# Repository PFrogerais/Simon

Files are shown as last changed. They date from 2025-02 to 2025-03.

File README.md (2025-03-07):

# Démonstration du Jeu Simon – Assemblé & Programmé
Dans cette vidéo, découvrez le jeu **Simon** entièrement assemblé et programmé !  

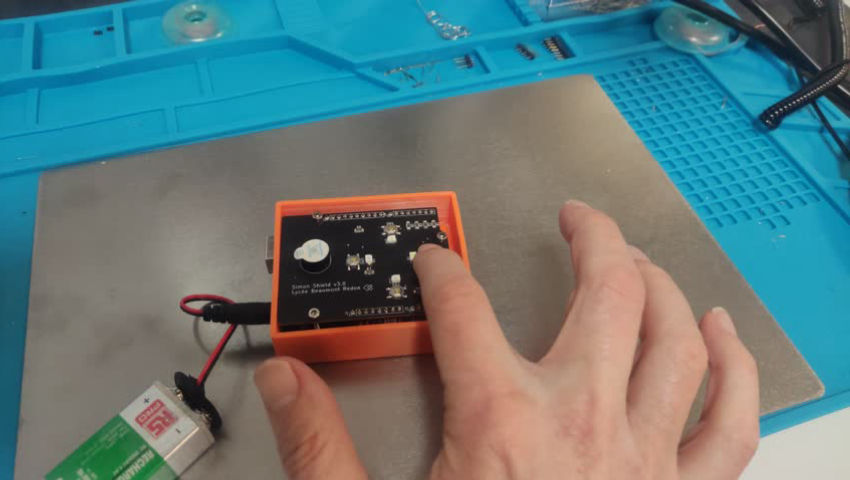
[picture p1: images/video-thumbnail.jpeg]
Voir la démonstration (https://tube-sciences-technologies.apps.education.fr/w/i4Xqwx69rhGFDRBjq2J4fU)


Ce projet, basé sur une carte Arduino, intègre :
- **4 LEDs** et **4 boutons** pour reproduire la séquence du jeu,
- Un **buzzer** pour les signaux sonores,
- Un **boîtier imprimé en 3D** réalisé sur mesure,

# Dossier de conception du shield Arduino

Voici un guide étape par étape pour concevoir et assembler la carte électronique intégrant des composants CMS (résistances et LED montées en surface) ainsi que des composants traversants (comme le connecteur Arduino et le buzzer). Ce procédé  inclut l'application manuelle de pâte à braser et le passage en four à refusion sans utilisation de stencil.

## 1. Génération des Fichiers de Fabrication

- **Fichiers Gerber :**
- Télécharger [fichiers de fabrication gerber Simon3.zip](hardware/kicad/simon3/production/simon3.zip)
- **Fabrication du PCB :**
- Envoyez ces fichiers à un fabricant de PCB (JLCPCB)

## 2. Nomenclature

| Reference | Value |  Qty |
|---|---|----- |
| BZ1 | Buzzer |  1 |
| D1 | LED RED |  1 |
| D2 | LED Green |  1 |
| D3 | LED Blue |  1 |
| D4 | LED Yellow |  1 |
| J1 | Power |  1 |
| J2,J4 | Digital/PWM  |  2 |
| J3 | Analog |  1 |
| R1,R2 | 160 |  2 |
| R3 | 100 |  1 |
| R4 | 150 |  1 |
| R5,R6,R7,R8 | 10k |  4 |
| SW1,SW2,SW3,SW4 | SW_Push |  4 |

[Nomenclature](hardware/kicad/simon3/simon3.csv)

## 4. Préparation à l’Assemblage

- **Nettoyage du PCB :**
  - Assurez-vous que la carte est propre et exempte de poussière ou d’empreintes.
- **Mise en place du poste de travail :**
  - Organisez votre matériel : pâte à braser (en seringue), fer à souder pour les composants traversants, four à refusion.
- **Documentation :**
  - Imprimez le schéma et/ou un plan de positionnement (layout) pour guider le placement des composants.
Implantation

# Brasage des composants

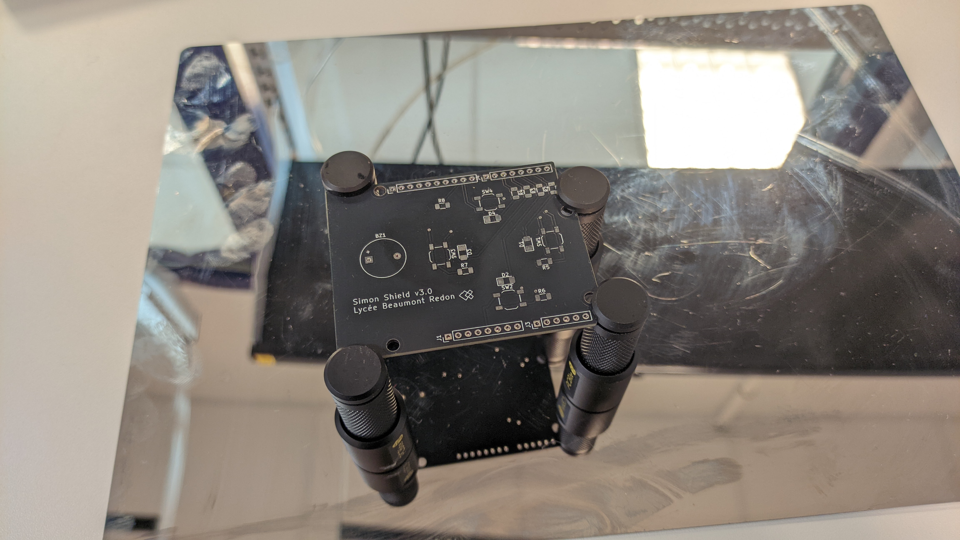
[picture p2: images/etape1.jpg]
carte à braser
 

## 1. Application de la Pâte à Braser (Sans Stencil)

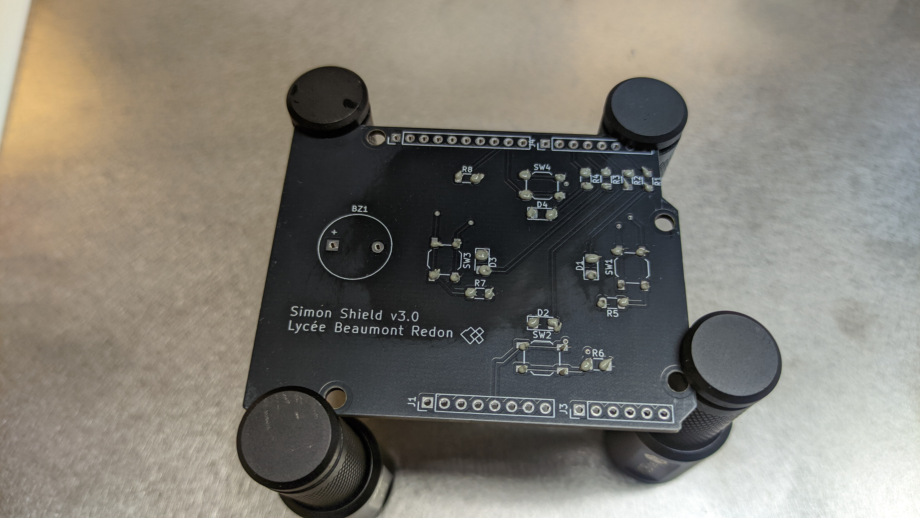
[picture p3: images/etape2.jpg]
Appliquer la pâte
 

- **Utilisation d’une seringue :**
  - À l’aide d’une seringue, déposez manuellement la pâte à braser sur chaque zone de montage des composants CMS.
  - Veillez à appliquer la quantité appropriée pour chaque pad afin d’éviter les ponts de soudure ou les soudures insuffisantes.
- **Précision :**
  - Pour les zones très fines, utilisez une seringue à embout fin et, si besoin, une loupe pour vérifier l’exactitude de l’application.

## 6. Placement des Composants CMS

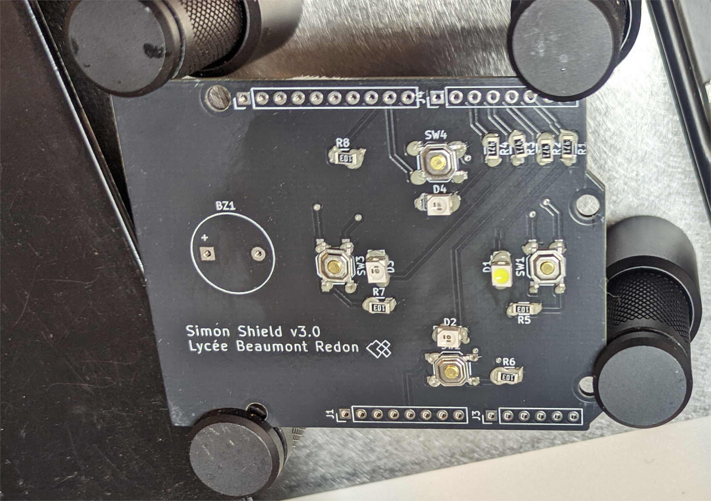
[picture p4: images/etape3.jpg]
Peupler les CMS


- **Positionnement :**
  - Placez délicatement les composants CMS (résistances, LED, etc.) sur les pads recouverts de pâte.
  - Vérifiez l’alignement et l’orientation (notamment pour les composants polarisés comme certaines LED).
- **Ajustement :**
  - Corrigez la position des composants si nécessaire avant le passage en four.

## 7. Passage en Four à Refusion

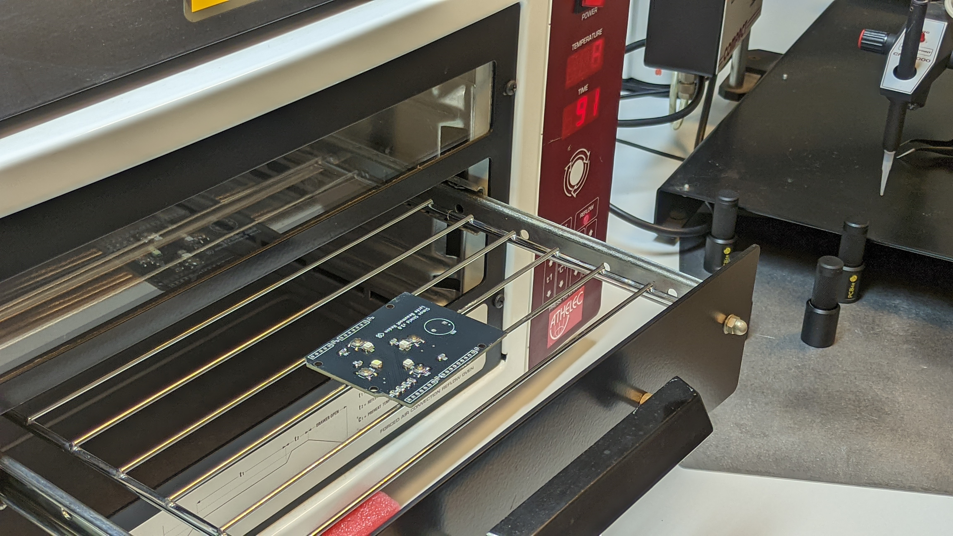
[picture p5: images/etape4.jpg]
Mettrer au four


- **Programmation de la courbe de chauffe :**

  - Programmez le four à refusion selon une courbe de température adaptée (phase de préchauffage, pic de température, et refroidissement contrôlé).

- **Refusion :**
  - Placez la carte dans le four et lancez le cycle.
  - Surveillez le processus pour vous assurer que la pâte à braser fond correctement et forme des joints solides.
- **Refroidissement :**
  - Laissez la carte refroidir progressivement pour éviter les contraintes thermiques.

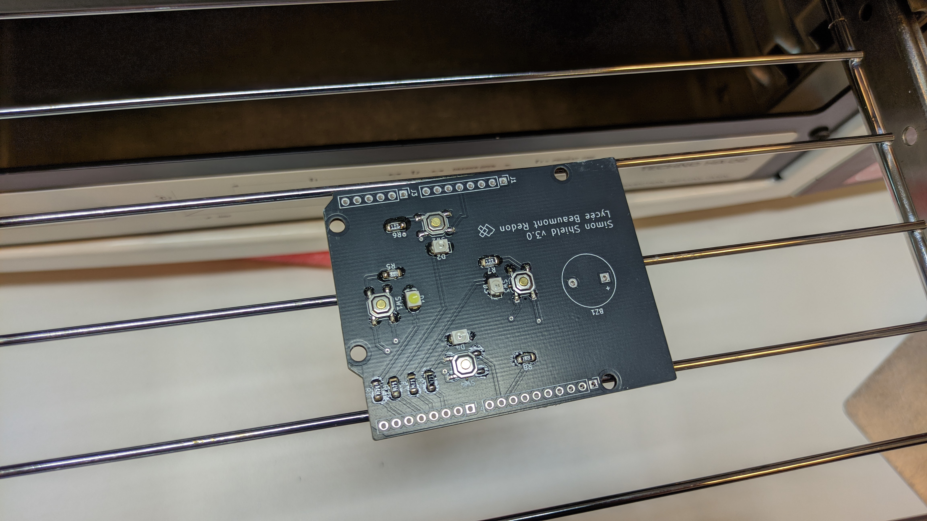
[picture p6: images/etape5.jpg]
Sortir du four


## 8. Soudure des Composants Traversants

- **Placement manuel :**
  - Après la refusion des composants CMS, positionnez les composants traversants (connecteur Arduino, buzzer, etc.) sur la carte.
- **Soudure :**
  - Utilisez un fer à souder pour souder manuellement ces composants.
  - Assurez-vous de réaliser des soudures nettes et sans ponts.
- Utilisation d'une carte Arduino HS pour pour maintenir le shield et les connecteurs 
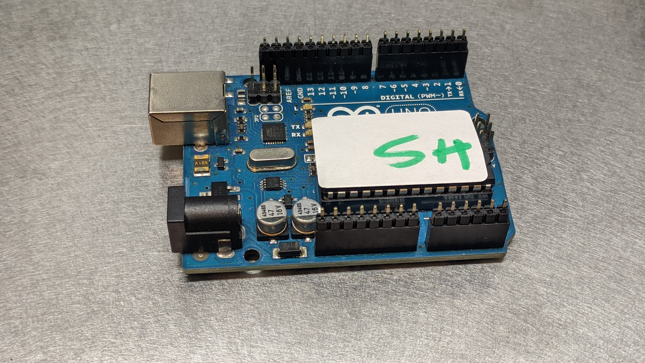
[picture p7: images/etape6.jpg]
Arduino HS

- Placer la carte par dessus 
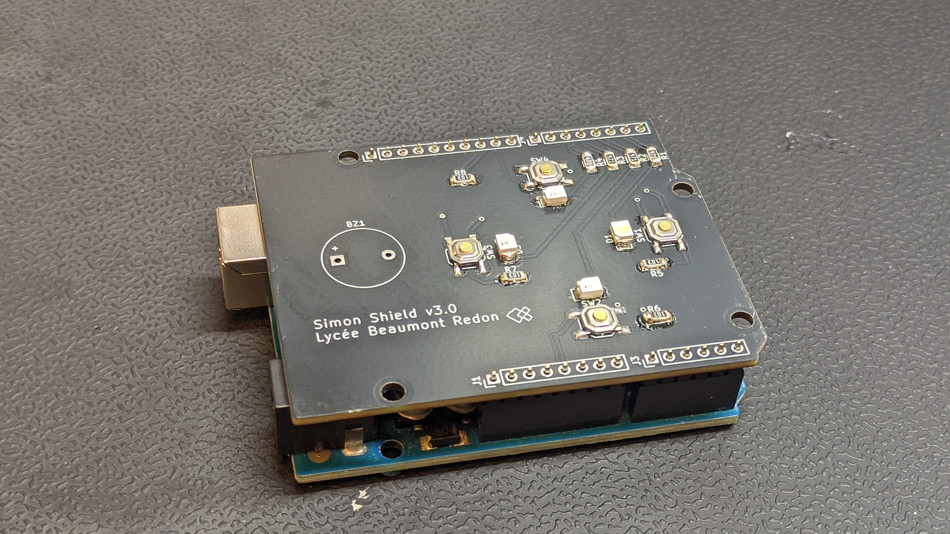
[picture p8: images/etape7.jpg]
Shield maintenu sur l'Arduino UNO

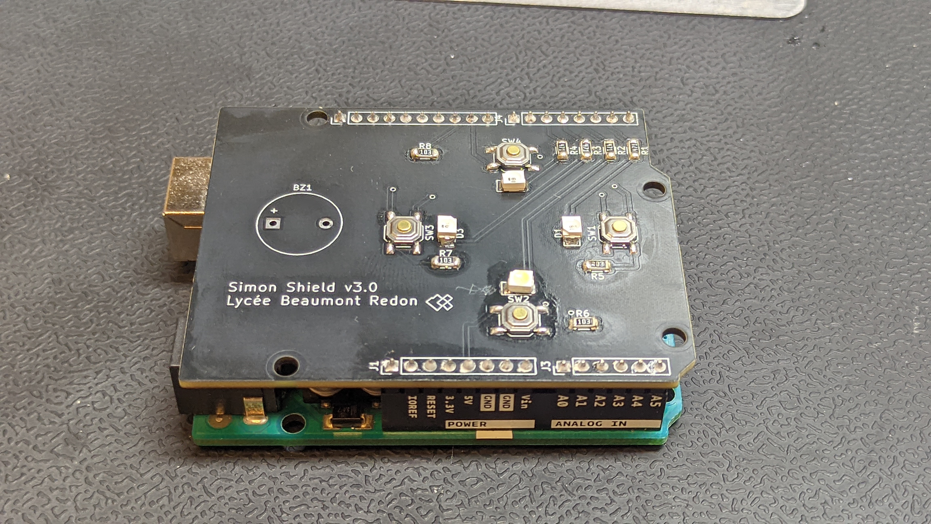
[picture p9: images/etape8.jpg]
Soudure du connecteur

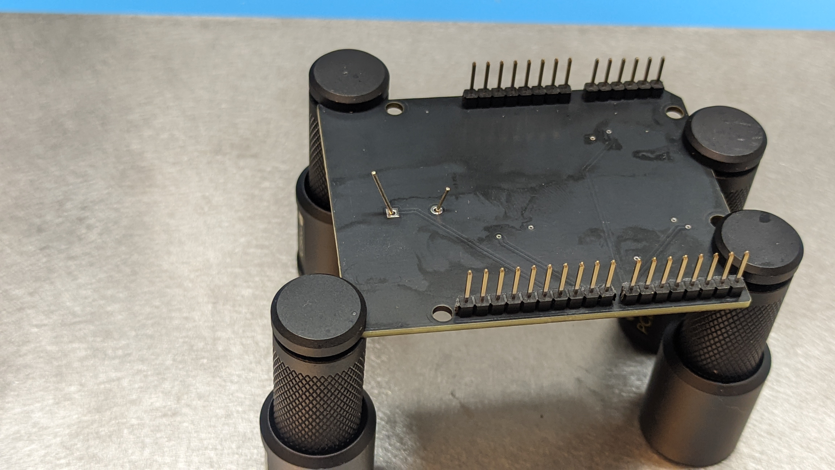
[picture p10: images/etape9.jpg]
Soudure du buzzer


## 9. Inspection et Tests

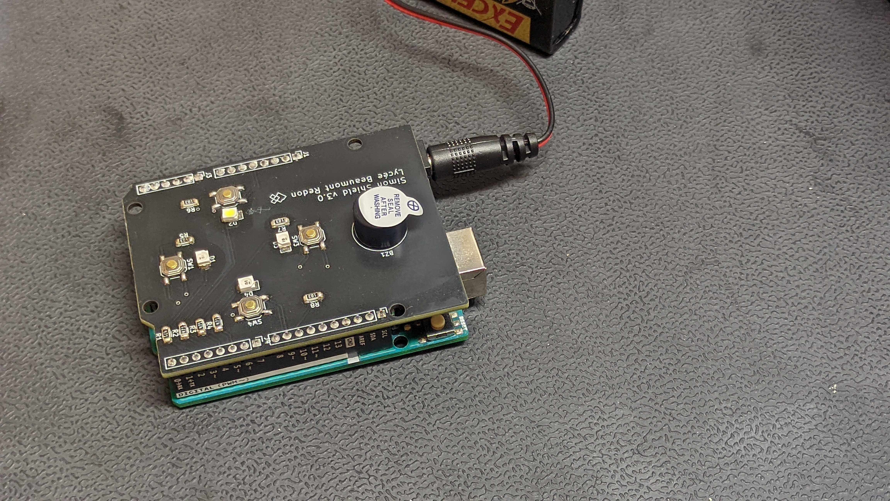
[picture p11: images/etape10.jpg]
Brasures Terminéee


- **Contrôle visuel :**

  - Inspectez la carte à l’aide d’une loupe ou d’un microscope pour vérifier la qualité des soudures (absence de ponts, bonne homogénéité des joints).
- **Retouches éventuelles :**
  - Réalisez des retouches manuelles si vous constatez des défauts.
- **Tests fonctionnels :**
  - Alimentez la carte et vérifiez le bon fonctionnement de l’ensemble du circuit (LED, buzzer, connecteur Arduino).
  - Mesurez les tensions et vérifiez la continuité des pistes si nécessaire.

# Conception du boitier en 3D

Cette section décrit les étapes d'assemblage de votre projet dans un boîtier imprimé en 3D. Le but est de fournir toutes les informations nécessaires pour intégrer les composants électroniques (Arduino UNO, shield, etc.) dans le boîtier final. Le modèle 3D du boîtier, au format STL, est mis à disposition pour que vous puissiez le préparer dans votre logiciel de découpe (slicer) et lancer l'impression 3D.

## Détail des étapes

1. **Modèle 3D du boîtier**

   - **Description :**  
     Vous disposez du fichier STL du boîtier, nommé ici "Boitier Simon". Ce fichier est utilisé avec un slicer pour préparer l'impression 3D de la pièce.
   - **Lien :**  
     [Boitier Simon](hardware/Boitier/simon_box_2-MainBox.stl)  
     En cliquant sur ce lien, vous accédez directement au fichier STL hébergé dans le répertoire `hardware/Boitier/` de votre dépôt GitHub.

2. **Ajouter les inserts à chaud à l'aide d'un fer à souder**

   - **Description :**  

     Avant de monter les composants, il est recommandé d'ajouter des inserts (des éléments métalliques ou en plastique spécialement conçus pour recevoir des vis) dans le boîtier.  
     Pour cela, on utilise un fer à souder qui, en chauffant les inserts, permet de les fixer solidement dans la matière imprimée.
   - **Illustration :**  

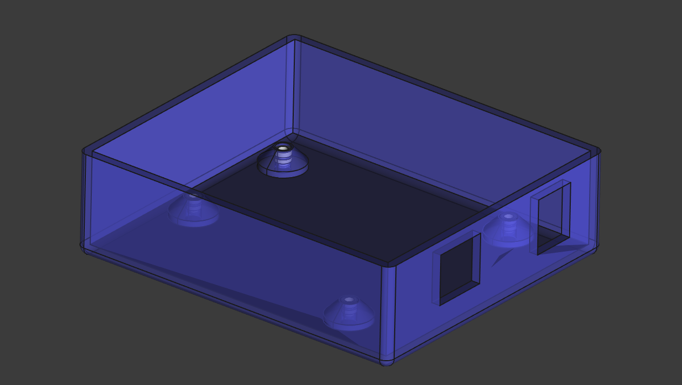
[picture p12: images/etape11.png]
Boitier + insert
      
     Cette image montre le boîtier dans lequel les inserts ont été placés, prêts à recevoir les fixations.

3. **Ajouter la carte Arduino UNO**
   - **Description :**  

     Une fois les inserts en place, la carte Arduino UNO est insérée dans le boîtier.  
     Cette étape assure que l'électronique de base du projet est correctement positionnée et prête à être connectée aux autres composants.

    - **Illustration :**  

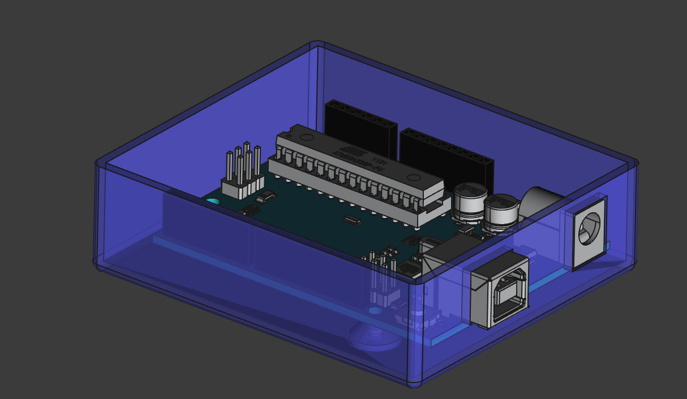
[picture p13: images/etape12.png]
Boitier + insert + UNO
       
     L'image illustre la carte Arduino UNO insérée dans le boîtier, avec les inserts déjà en place.

4. **Ajouter le shield**

   - **Description :**  

     Le shield, qui est une extension pour l'Arduino, est ensuite ajouté sur la carte.  
     Cette étape complète l'intégration de l'électronique, permettant d'ajouter des fonctionnalités supplémentaires (par exemple, gestion d'entrées/sorties, alimentation, etc.).
   - **Illustration :**  
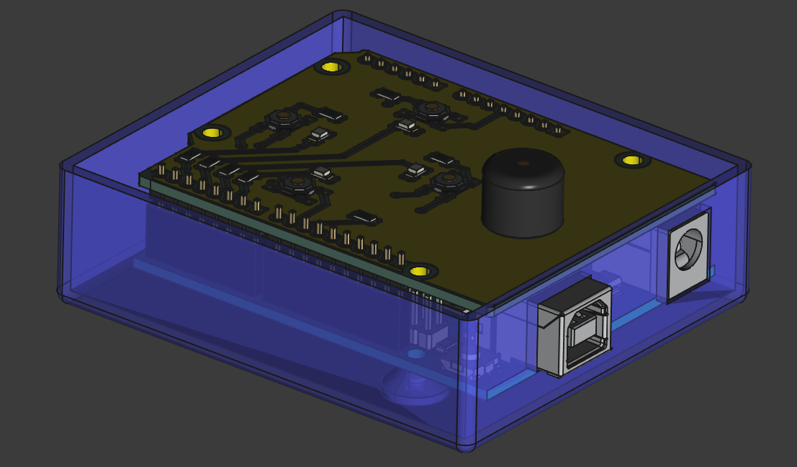
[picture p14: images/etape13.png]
Boitier + insert + UNO+ Shield
     
     L'image montre le boîtier avec la carte Arduino UNO et le shield monté, indiquant l'évolution de l'assemblage.

5. **Visser les 4 vis dans les inserts**

   - **Description :**  
     Pour finaliser l'assemblage, 4 vis sont insérées dans les inserts prévus à cet effet.  
     Ces vis servent à fixer solidement l'ensemble des composants dans le boîtier, garantissant une bonne stabilité mécanique.
   - **Illustration :**  
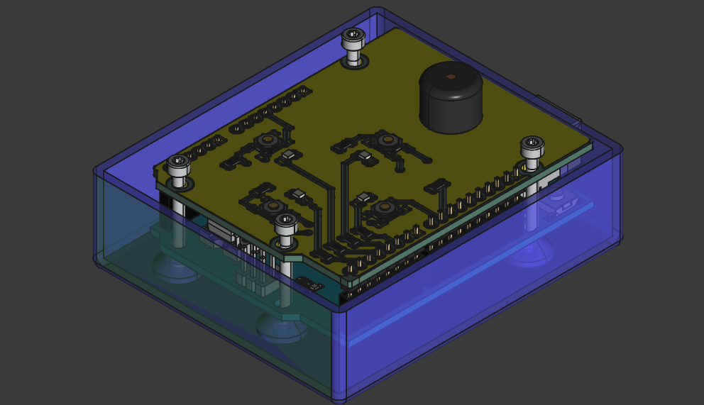
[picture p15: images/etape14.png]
Boitier + insert + UNO+ Shield + Vis
       
     Cette dernière image montre l'assemblage complet, où l'ensemble des composants (boîtier, inserts, Arduino, shield) est maintenu par les vis.

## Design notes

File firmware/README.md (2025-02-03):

# Projet Simon

Ce projet implémente le célèbre jeu **Simon** sur une plateforme Arduino. Le but du jeu est de reproduire une séquence de LED et de sons générée aléatoirement par le système. À chaque tour, une nouvelle note (LED + son) est ajoutée à la séquence, et le joueur doit répéter la séquence dans le bon ordre en appuyant sur les boutons correspondants. En cas d'erreur, une séquence "Game Over" est jouée et la partie redémarre.

## Matériel nécessaire

- **Arduino Uno** (ou toute autre carte compatible Arduino)
- **4 LEDs** (par exemple : rouge, vert, bleu, jaune)
- **4 Boutons-poussoirs (BP)**
- **1 Buzzer** (pour la sortie sonore)
- **Résistances** (pour les LEDs et éventuellement pour les boutons selon votre montage)
- **Câbles de connexion** et une **breadboard**

## Schéma de connexion
Schéma structurel

Les broches utilisées dans ce projet sont définies dans le code :

- **LEDs :**
  - LED1 : Broche 2
  - LED2 : Broche 3
  - LED3 : Broche 4
  - LED4 : Broche 5

- **Boutons :**
  - BP1 : Broche 6
  - BP2 : Broche 7
  - BP3 : Broche 8
  - BP4 : Broche 9

- **Buzzer :**
  - BUZZ : Broche 10

> **Note :** Assurez-vous de connecter les composants correctement et d'utiliser des résistances adaptées pour protéger les LEDs et les boutons.

## Description du code

Le code se divise en plusieurs fonctions :

- **setup()**  
  Configure les broches en mode `INPUT` ou `OUTPUT` et initialise la communication série.

- **Ajouter_Note()**  
  Ajoute une nouvelle note aléatoire à la séquence `melody`.

- **Simon_Play()**  
  Parcourt la séquence `melody` et joue la note correspondante en allumant la LED associée et en jouant un son via le buzzer.

- **Scan_Boutons() & Bouton_Test()**  
  Ces fonctions gèrent la détection des appuis sur les boutons. Chaque bouton est lié à une LED et à une tonalité spécifique.

- **GameOver()**  
  Joue une séquence de fin pour signaler que le joueur a fait une erreur dans la saisie de la séquence.

- **loop()**  
  La boucle principale du jeu qui :
  1. Ajoute une nouvelle note à la séquence.
  2. Joue la séquence complète.
  3. Attend que le joueur reproduise la séquence en scannant les boutons.  
     En cas d'erreur, la séquence Game Over est déclenchée et la partie redémarre.

## Comment utiliser le projet

1. **Branchement :**  
   Réalisez le montage en connectant les LEDs, boutons et buzzer aux broches indiquées. Vérifiez que tous les composants sont bien alimentés et que les connexions sont sécurisées.

2. **Téléversement du code :**  
   - Ouvrez l’IDE Arduino.
   - Copiez le code source dans un nouveau sketch.
   - Sélectionnez le bon modèle d’Arduino et le port série correspondant.
   - Téléversez le sketch sur la carte Arduino.

3. **Lancement du jeu :**  
   Une fois le programme téléversé, la carte Arduino démarre automatiquement le jeu.
   - La séquence commence par l'ajout d'une note aléatoire.
   - La séquence est affichée via les LEDs et le buzzer.
   - Appuyez sur les boutons correspondants pour reproduire la séquence.  
     *Exemple :* Si la LED1 s’allume, appuyez sur le bouton BP1.
   - Si la séquence est correctement reproduite, une nouvelle note est ajoutée et le jeu continue.
   - En cas d'erreur, le signal Game Over est joué, et la séquence redémarre.

4. **Observation via le moniteur série :**  
   Le moniteur série affiche certaines informations (comme les tonalités jouées ou le message "Game Over"). Pour l’ouvrir, cliquez sur **Outils > Moniteur Série** dans l’IDE Arduino.

## Personnalisation

- **Modifier les tonalités :**  
  Les tonalités sont définies dans le tableau `son[]`. Vous pouvez modifier ces valeurs pour changer les sons émis par le buzzer.

- **Modifier la vitesse du jeu :**  
  Ajustez les délais (`delay()`) dans les fonctions `Simon_Play()`, `Bouton_Test()`, et `GameOver()` pour rendre le jeu plus rapide ou plus lent.

## Remarques

- **Débounce des boutons :**  
  Un délai de 20 ms est utilisé dans la fonction `Bouton_Test()` pour éviter les rebonds (détection multiple d’un même appui). Selon votre montage, vous pourriez avoir besoin d'ajuster cette valeur.

- **Extensibilité :**  
  Vous pouvez étendre ce projet en ajoutant d'autres fonctionnalités comme un affichage sur écran LCD, une gestion des scores, ou encore une difficulté progressive.

## Conclusion

Ce projet Simon est un excellent moyen de se familiariser avec la programmation sur Arduino, la gestion des entrées/sorties et la création d'interfaces interactives simples. Amusez-vous bien et n'hésitez pas à expérimenter pour l'améliorer ou le personnaliser !

---

*Date de création : 03/02/2025*

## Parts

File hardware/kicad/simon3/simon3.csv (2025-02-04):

Reference | Value | Datasheet | Footprint | Qty | DNP
BZ1 | Buzzer | ~ | Buzzer_Beeper:Buzzer_12x9.5RM7.6 | 1
D1 | LED RED | ~ | LED_SMD:LED_1206_3216Metric_Pad1.42x1.75mm_HandSolder | 1
D2 | LED Green | ~ | LED_SMD:LED_1206_3216Metric_Pad1.42x1.75mm_HandSolder | 1
D3 | LED Blue | ~ | LED_SMD:LED_1206_3216Metric_Pad1.42x1.75mm_HandSolder | 1
D4 | LED Yellow | ~ | LED_SMD:LED_1206_3216Metric_Pad1.42x1.75mm_HandSolder | 1
J1 | Power |  | Connector_PinHeader_2.54mm:PinHeader_1x08_P2.54mm_Vertical | 1
J2,J4 | Digital/PWM |  | -- valeurs mixtées -- | 2
J3 | Analog | ~ | Connector_PinHeader_2.54mm:PinHeader_1x06_P2.54mm_Vertical | 1
R1,R2 | 160 | ~ | Resistor_SMD:R_1206_3216Metric | 2
R3 | 100 | ~ | Resistor_SMD:R_1206_3216Metric | 1
R4 | 150 | ~ | Resistor_SMD:R_1206_3216Metric | 1
R5,R6,R7,R8 | 10k | ~ | Resistor_SMD:R_1206_3216Metric | 4
SW1,SW2,SW3,SW4 | SW_Push | ~ | Button_Switch_SMD:SW_SPST_TL3342 | 4

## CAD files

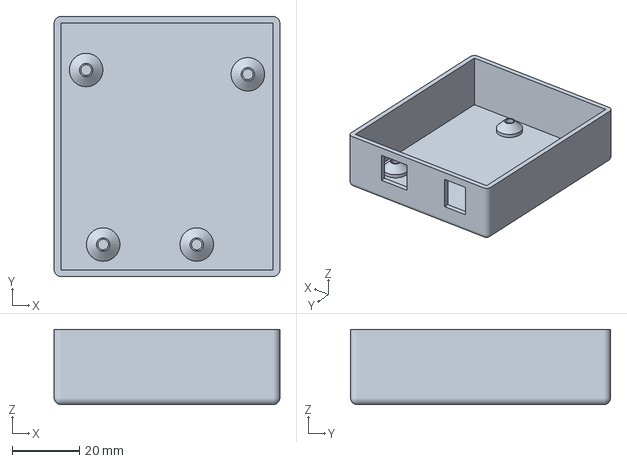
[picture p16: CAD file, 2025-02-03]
hardware/Boitier/simon_box_2-MainBox.3mf
67.3 x 77.6 x 22.4 mm

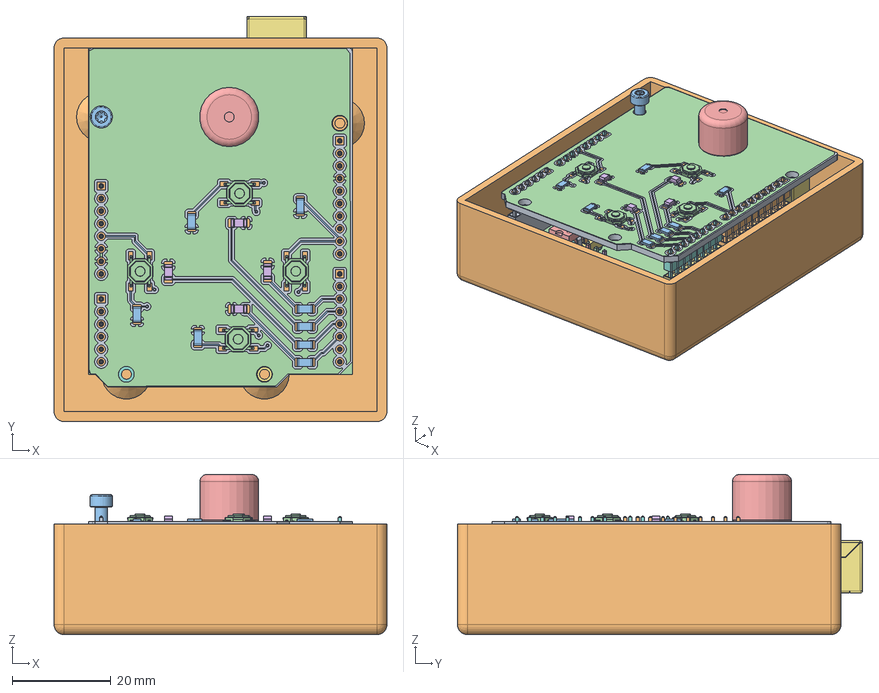
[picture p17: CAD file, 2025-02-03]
hardware/Boitier/simon_box_2.FCStd
67.3 x 81.9 x 32.4 mm
Pcb_5655
topPads_5655
topTracks_5655
topZones_5655
botPads_5655
botTracks_5655
botZones_5655
${REFERENCE}_PinHeader_1x08_P254mm_Vertical_null x 2
${REFERENCE}_PinHeader_1x06_P254mm_Vertical_null
${REFERENCE}_PinHeader_1x10_P254mm_Vertical_null
${REFERENCE}_R_1206_3216Metric_null x 8
${REFERENCE}_SW_SPST_TL3342_null x 4
+_Buzzer_12x95RM76_null
${REFERENCE}_LED_1206_3216Metric_null x 4
M2.5x3.5-Insert
M2.5x3.5-Insert071
M2.5x3.5-Insert072
M2.5x3.5-Insert073
M2.5x20-Screw
unoboard blue
47uf CAP Dcase
47uf CAP Dcase001
USB SHELL
USB core
usb top contact
usb btm contact
usb btm contact001
usb top contact001
power jack
power jack001
47uf CAP Dcase003
47uf CAP Dcase004
crystal
2pin_header__02
nano - reg
led
led001
2pin_header__003
dip28
dip socket pin
dip socket pin001
dip socket pin002
dip socket pin003
dip socket pin004
dip socket pin005
dip socket pin006
dip socket pin007
dip socket pin008
dip socket pin009
dip socket pin010
dip socket pin011
dip socket pin012
dip socket pin013
dip socket pin014
dip socket pin015
dip socket pin016
dip socket pin017
dip socket pin018
dip socket pin019
dip socket pin020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

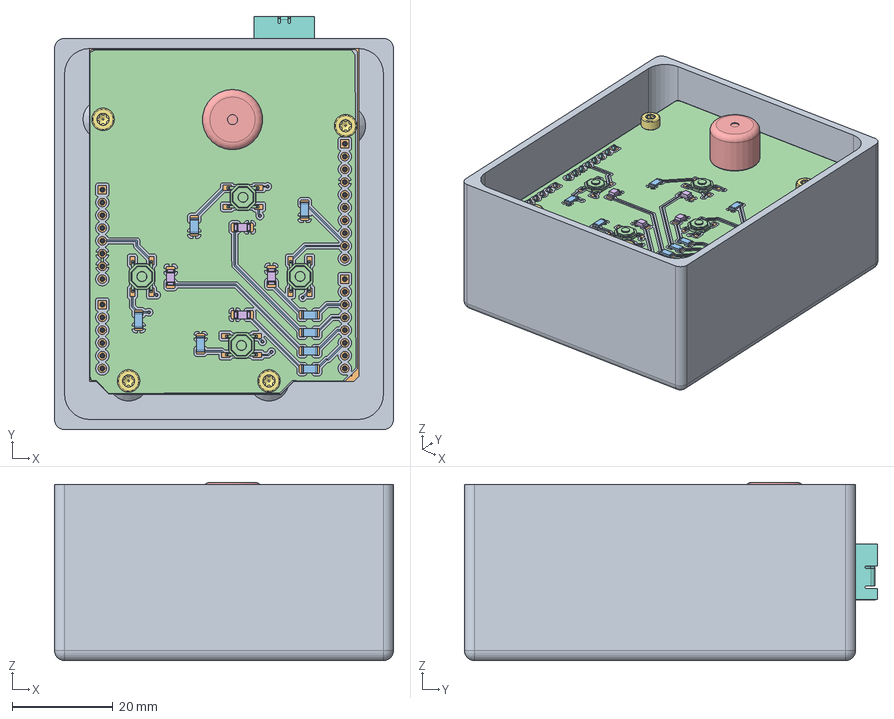
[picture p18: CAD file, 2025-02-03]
hardware/Boitier/simon_box.FCStd
67.5 x 82.2 x 35.4 mm
Botom
Micro_USB
SW3dPS-0805_SMD_Resistor
User_Library-led_0805-blue
Extruded
Extruded001
Extruded002
Extruded003
Extruded004
Extruded005
SW3dPS-0805_SMD_Resistor001
User_Library-led_0805-blue001
User_Library-DO-214Aa_SMA
capicitor_5x5.5x1.4
Base_\X2\03A6\X0\5Capacitor
capicitor_5x5.5x1.005
Base_\X2\03A6\X0\5Capacitor001
SW3DPS-SOT-223-DEFAULT
User_Library-HC49S-1_Fusion
User_Library-HC49S-1_Fusion001
User_Library-HC49S-1_Fillet
User_Library-HC49S-1_Fillet002
User_Library-HC49S-1_Fusion003
User_Library-HC49S-1_Fusion004
User_Library-HC49S-1_Fillet003
User_Library-HC49S-1_Fillet004
User_Library-SOIC-16-1
SW3dPS-DIP28-300
4301x20508x6
SW3dPS-0805_SMD_Resistor002
SW3dPS-0805_SMD_Resistor003
SW3dPS-0805_SMD_Resistor004
SW3dPS-0805_SMD_Resistor005
SW3dPS-0805_SMD_Resistor006
User_Library-led_0805-blue002
User_Library-led_0805-blue003
SW3dPS-dc_range_-_dc_connector[4840.2201]
SW3dPS-dc_range_-_dc_connector[4840.2201]001
c-0292304-01-b-3d
0805_SMD_Capacitor
0805_SMD_Capacitor001
0805_SMD_Capacitor002
0805_SMD_Capacitor003
0805_SMD_Capacitor004
0805_SMD_Capacitor005
0805_SMD_Capacitor006
0805_SMD_Capacitor007
6130xx11821_PIN
6130xx11821_PIN001
6130xx11821_PIN002
6130xx11821_PIN003
6130xx11821_PIN004
6130xx11821_PIN005
6130xx11821_PIN006
6130xx11821_PIN007
6130xx11821_PIN008
6130xx11821_PIN009
6130xx11821_PIN010
6130xx11821_PIN011
6130xx11821_PIN012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

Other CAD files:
hardware/Boitier/Simon_assemblage.FCStd
hardware/Boitier/simon_box_2-MainBox.stl

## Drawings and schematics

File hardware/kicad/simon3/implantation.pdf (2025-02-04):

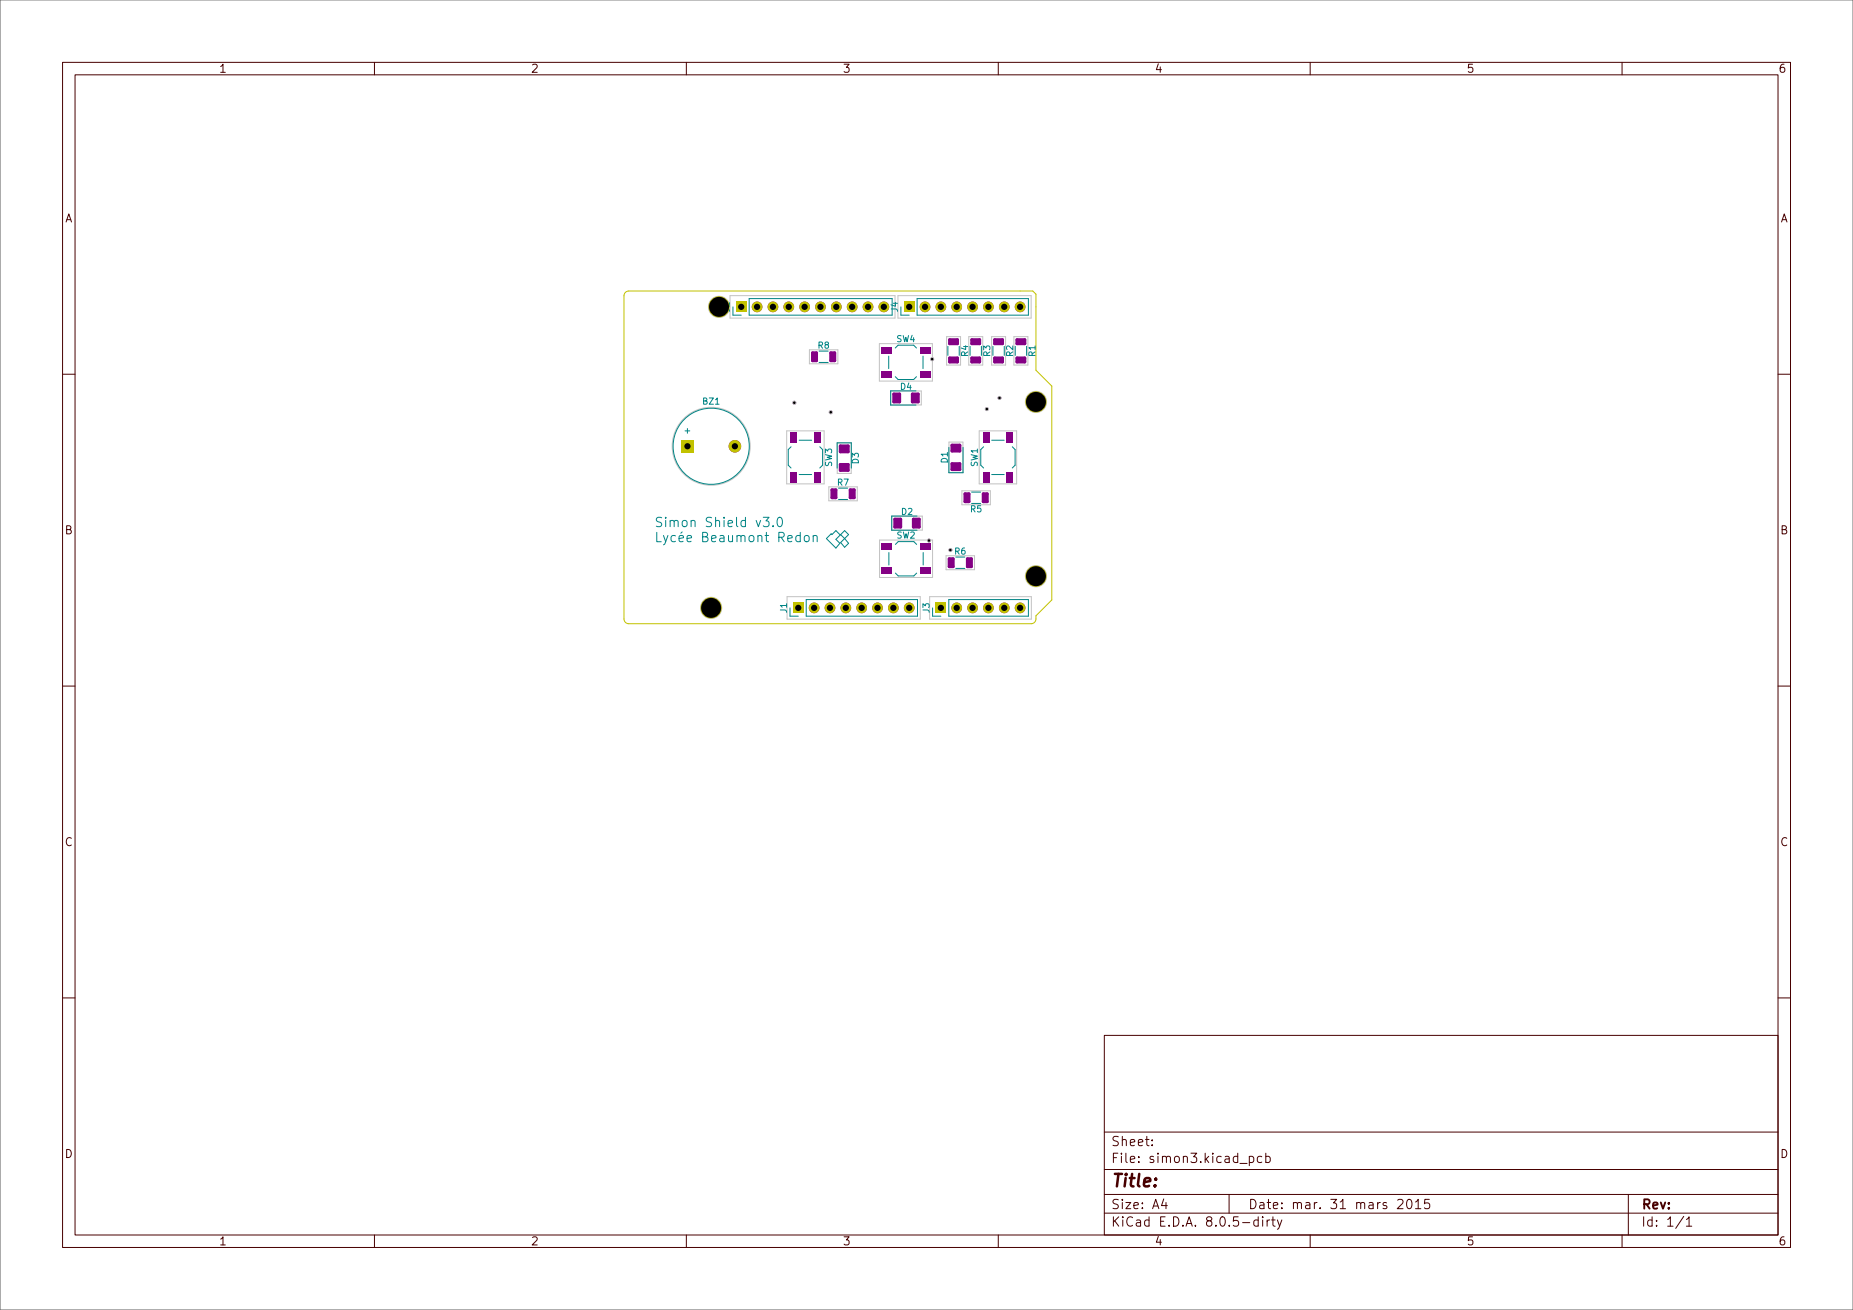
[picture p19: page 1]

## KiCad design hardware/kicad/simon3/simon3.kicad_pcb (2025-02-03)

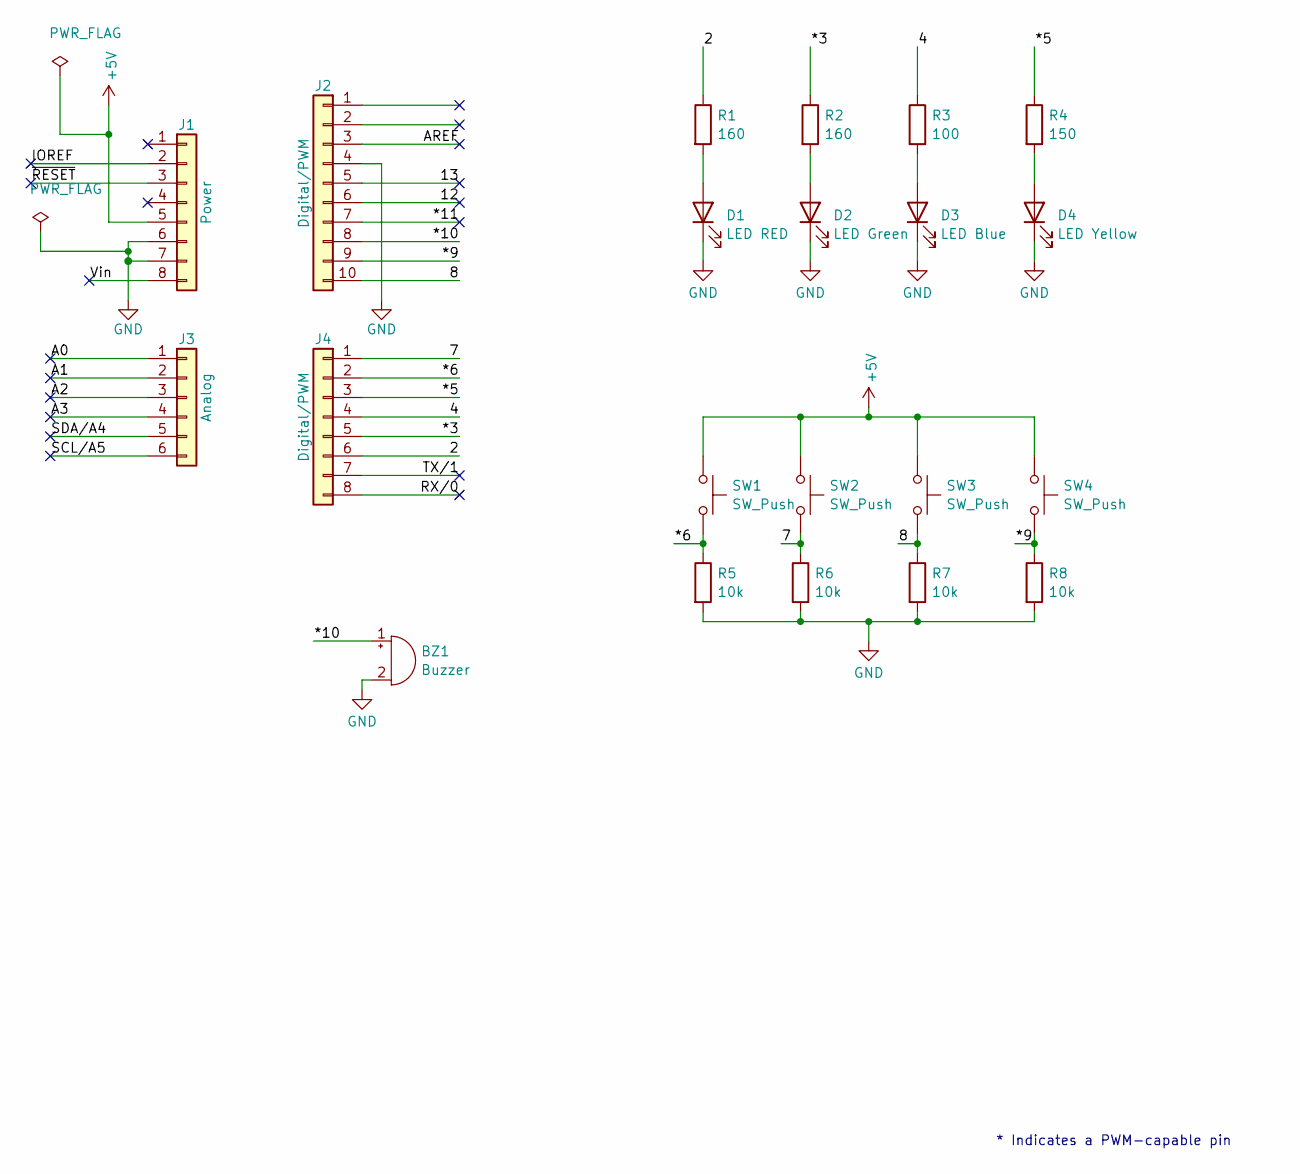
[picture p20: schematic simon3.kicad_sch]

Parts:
BZ1: Buzzer; Buzzer_12x9.5RM7.6
D1: LED RED; LED_1206_3216Metric_Pad1.42x1.75mm_HandSolder
D2: LED Green; LED_1206_3216Metric_Pad1.42x1.75mm_HandSolder
D3: LED Blue; LED_1206_3216Metric_Pad1.42x1.75mm_HandSolder
D4: LED Yellow; LED_1206_3216Metric_Pad1.42x1.75mm_HandSolder
J1: Power; PinHeader_1x08_P2.54mm_Vertical
J2: Digital/PWM; PinHeader_1x10_P2.54mm_Vertical
J3: Analog; PinHeader_1x06_P2.54mm_Vertical
J4: Digital/PWM; PinHeader_1x08_P2.54mm_Vertical
R1, R2: 160; R_1206_3216Metric
R3: 100; R_1206_3216Metric
R4: 150; R_1206_3216Metric
R5, R6, R7, R8: 10k; R_1206_3216Metric
SW1, SW2, SW3, SW4: SW_Push; SW_SPST_TL3342

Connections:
+5V: J1.5, SW1.1, SW2.1, SW3.1, SW4.1
/2: J4.6, R1.1
/4: J4.4, R3.1
/7: J4.1, R6.1, SW2.2
/8: J2.10, R7.1, SW3.2
/12: J2.6
/13: J2.5
/*3: J4.5, R2.1
/*5: J4.3, R4.1
/*6: J4.2, R5.1, SW1.2
/*9: J2.9, R8.1, SW4.2
/*10: BZ1.1 (+), J2.8
/*11: J2.7
/A0: J3.1
/A1: J3.2
/A2: J3.3
/A3: J3.4
/AREF: J2.3
/IOREF: J1.2
/RX/0: J4.8
/SCL/A5: J3.6
/SDA/A4: J3.5
/TX/1: J4.7
/Vin: J1.8
/~RESET: J1.3
GND: BZ1.2 (-), D1.1 (K), D2.1 (K), D3.1 (K), D4.1 (K), J1.6, J1.7, J2.4, R5.2, R6.2, R7.2, R8.2
unnamed: D1.2 (A), R1.2
unnamed: D2.2 (A), R2.2
unnamed: D3.2 (A), R3.2
unnamed: D4.2 (A), R4.2

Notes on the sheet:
* Indicates a PWM-capable pin

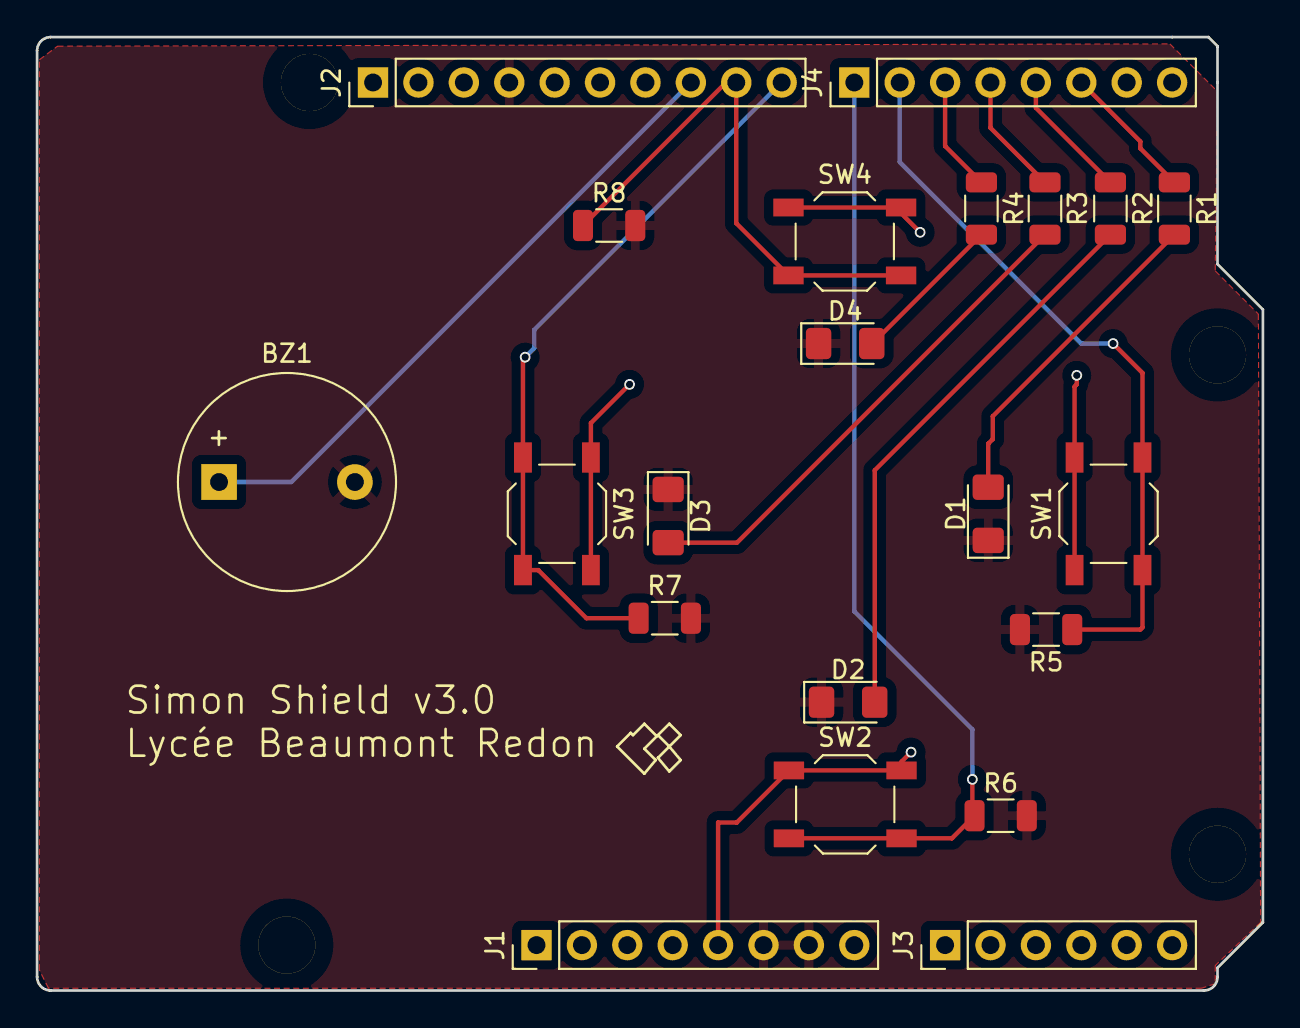
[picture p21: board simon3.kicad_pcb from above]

Board: 2 copper layers, 68.6 x 53.3 mm, 25 parts (0 on the bottom side), 15 nets.

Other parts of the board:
MH1, MH2, MH3, MH4: MountingHole_3.2mm

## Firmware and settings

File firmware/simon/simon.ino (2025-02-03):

/*
Projet : Simon 
DATE : 03/02/2025

██████╗     ███████╗██████╗  ██████╗  ██████╗ ███████╗██████╗  █████╗ ██╗███████╗
██╔══██╗    ██╔════╝██╔══██╗██╔═══██╗██╔════╝ ██╔════╝██╔══██╗██╔══██╗██║██╔════╝
██████╔╝    █████╗  ██████╔╝██║   ██║██║  ███╗█████╗  ██████╔╝███████║██║███████╗
██╔═══╝     ██╔══╝  ██╔══██╗██║   ██║██║   ██║██╔══╝  ██╔══██╗██╔══██║██║╚════██║
██║         ██║     ██║  ██║╚██████╔╝╚██████╔╝███████╗██║  ██║██║  ██║██║███████║
╚═╝         ╚═╝     ╚═╝  ╚═╝ ╚═════╝  ╚═════╝ ╚══════╝╚═╝  ╚═╝╚═╝  ╚═╝╚═╝╚══════╝
                                                                                 

                                                                                 

L'objectif de ce programme est de reproduire le comportement du jeu SIMON,
4 LEDs et 4 BP Associes et un Buzzer 


*/



// Definitions des broches connectees aux LED
const int LED1 = 2;
const int LED2 = 3;
const int LED3 = 4;
const int LED4 = 5;

// Definition des broche connectees aux BP
const int BP1 = 6;
const int BP2 = 7;
const int BP3 = 8;
const int BP4 = 9;

const int BUZZ = 10;

int melody[100] = {0};
int son[] = {230, 300, 400, 500};
int k = 0;

void setup()
{
  pinMode(LED1, OUTPUT);
  pinMode(LED2, OUTPUT);
  pinMode(LED3, OUTPUT);
  pinMode(LED4, OUTPUT);

  pinMode(BP1, INPUT);
  pinMode(BP2, INPUT);
  pinMode(BP3, INPUT);
  pinMode(BP4, INPUT);

  pinMode(BUZZ,OUTPUT);

  Serial.begin(9600);
}

// Ajoute une nouvelle note aleatoirement a la melody

void Ajouter_Note()
{
   int n = random(2,6); // Correspond aux LEDS
   melody[k] = n;
   k++;
}

// Le jeu Joue la melodie et led LEDs associees
//
void Simon_Play(void)
{
   for (int i=0; i<k; i++)
   {
      digitalWrite(melody[i],HIGH);
      Serial.print(son[melody[i]-2]);
      tone(BUZZ, son[melody[i]-2]); 
      delay(300);
      noTone(BUZZ);
      Eteindre_LED();
      delay(200);
   }
}

// Sequence de fin lorsque le joueur perd
//
void GameOver(void)
{
  for(int i = 0; i<4; i++)
  {
    Allumer_LED();
    tone(BUZZ,son[i]);
    delay(100);
    Eteindre_LED();
    noTone(BUZZ);
    delay(100);
  }
}
// Fonction loop() 
void loop()
{
  Ajouter_Note();
  Simon_Play();
  for (int i=0; i<k; i++)
  {
      int bouton_saisi = Scan_Boutons();
      if (bouton_saisi != melody[i]-1)
      {
         Serial.println("Game Over");
         GameOver();
         delay(2000);
         k=0;
      }
   delay(1000);
  }
  //
  delay(200);
  //Serial.println(bouton_saisi);
}

// Fonction permettant l'extinction de toutes les LEDs
void Eteindre_LED(void)
{
  digitalWrite(LED1, LOW);
  digitalWrite(LED2, LOW);
  digitalWrite(LED3, LOW);
  digitalWrite(LED4, LOW);
}

// Fonction permettant d'allumer toutes les LEDS
void Allumer_LED(void)
{
  digitalWrite(LED1, HIGH);
  digitalWrite(LED2, HIGH);
  digitalWrite(LED3, HIGH);
  digitalWrite(LED4, HIGH);
}

// Fonction Bouton_Test(BP, LED) renvoie
// 1 si Appui et allume la LED associee
// 0 sinon
int Bouton_Test(int BP, int LED)
{
    int etat_bouton = digitalRead(BP);
    delay(20);
    if(etat_bouton == 1)
    {
      tone(BUZZ,son[LED-2]);
      digitalWrite(LED,HIGH);
      while(etat_bouton==1)
      {
        etat_bouton = digitalRead(BP);
        delay(10);
      }
      return 1;
    }
    else
    {
      return 0;
    }
}

// Fonction verifiant quel bouton est appuye
// Renvoie 1 -> BP1, 2-> BP2 ...
int Scan_Boutons(void)
{
  int bouton_saisi = 0;
  while(bouton_saisi == 0)
  {
    int etat_bouton = Bouton_Test(BP1,LED1);
    if(etat_bouton == 1)
    {
      bouton_saisi = 1;
    }
    if(Bouton_Test(BP2,LED2)) // Ecriture plus condensee
    {
      bouton_saisi = 2;
    }
    if(Bouton_Test(BP3,LED3))
    {
      bouton_saisi = 3;
    }
    if(Bouton_Test(BP4,LED4))
    {
      bouton_saisi = 4;
    }
  }
  noTone(BUZZ);
  Eteindre_LED();
  return bouton_saisi;
}

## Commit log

2025-02-03 Ajout des projet FreeCAD et kicad du boitier
    [simon3.kicad_pcb, simon3.kicad_sch, simon_box.FCStd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]
2025-02-03 Ajout partie Arduino
2025-02-03 Ajout README pour arduino
2025-02-03 Ajout clours simon.svg
    [simon3.kicad_sch]
2025-02-04 ajout nomenclature
    [simon3.csv]
2025-02-04 modif insertion des image
2025-02-04 images boitier stl
    [simon_box_2-MainBox.stl]
2025-02-09 Ajout assemblage modif Readme
    [Nouveau.FCStd, Simon_assemblage.FCStd, Simon_assemblage2.FCStd]
2025-02-12 rev minneurs
    [Simon_assemblage.FCStd]
